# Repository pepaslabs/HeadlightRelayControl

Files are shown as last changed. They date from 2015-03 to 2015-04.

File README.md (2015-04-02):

# HeadlightRelayControl

A circuit board to control automotive headlight [relays](http://en.wikipedia.org/wiki/Relay).

## License

This board design is [Open-Source Hardware](http://www.oshwa.org/definition/).  It is licensed under the [MIT License](http://opensource.org/licenses/MIT).  It was designed by Jason Pepas.

# Board design v3

In this iteration of the board, the current-limiting resistors are replaced with constant-current sinks.

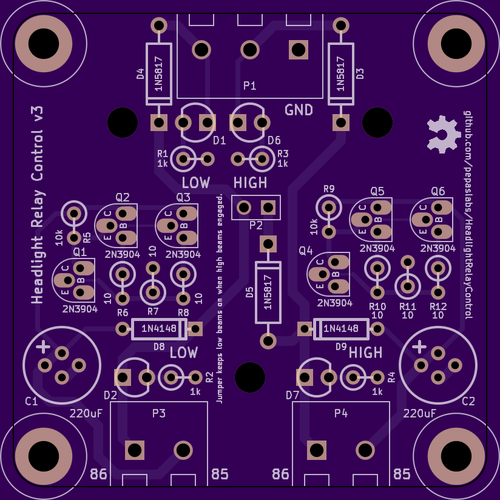
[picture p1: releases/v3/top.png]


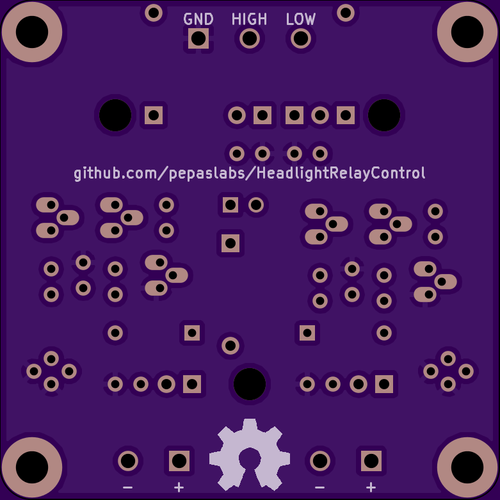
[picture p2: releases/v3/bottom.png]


(*Board renders courtesy of [OSHPark](https://oshpark.com/shared_projects/iHltO6hv)*)

## Gerbers

[gerbers.zip](releases/v3/gerbers.zip)

## Schematic

[PDF](releases/v3/HeadlightRelayControl_schematic.pdf).

# Board design v2

This was the first iteration of the design (which had no mistakes!).

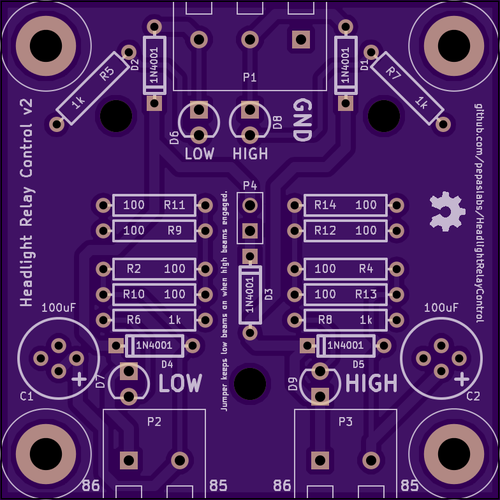
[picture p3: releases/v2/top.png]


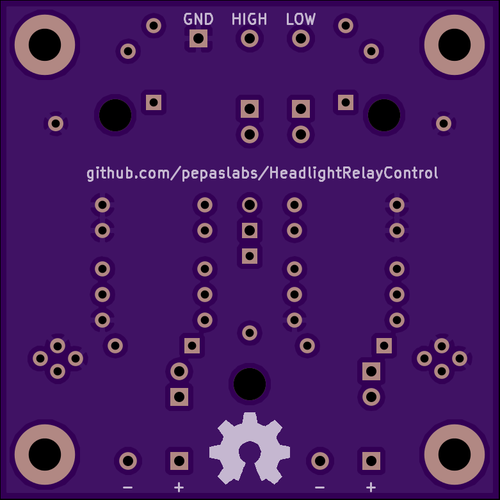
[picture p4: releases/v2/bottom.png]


(*Board renders courtesy of [OSHPark](https://oshpark.com/shared_projects/l73fKEFv)*)

## Gerbers

[gerbers.zip](releases/v2/gerbers.zip)

## Schematic

[PDF](releases/v2/HeadlightRelayControl_schematic.pdf).

# Board design v1

(This release had an error and is deprecated.)

# Designing this circuit in LTSpice

Let's design this circuit using [LTSpice](http://www.linear.com/ltspice).

Start with the following basic circuit.  The [inductor](http://en.wikipedia.org/wiki/Inductor) L1 represents the coil inside of the relay.

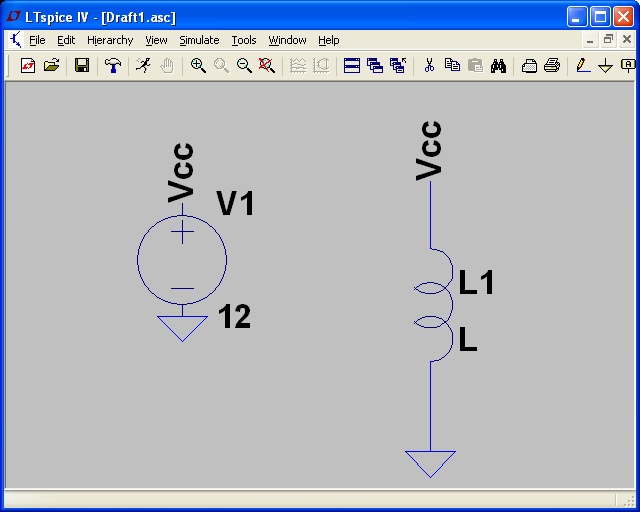
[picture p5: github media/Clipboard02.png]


## Specifying the relay coil parameters

Before we can simulate this circuit, we need to know some characteristics of the relay coil.  Specifically, we need to know the [inducatance](http://en.wikipedia.org/wiki/Inductance) and the [resistance](http://en.wikipedia.org/wiki/Electrical_resistance_and_conductance).

Here I've measured the inductance of a typical 12 Volt, 30 Amp automotive relay to be about 132 millihenries (using a cheap [LC100-A](http://www.ebay.com/sch/i.html?_nkw=LC100-A) meter from eBay):

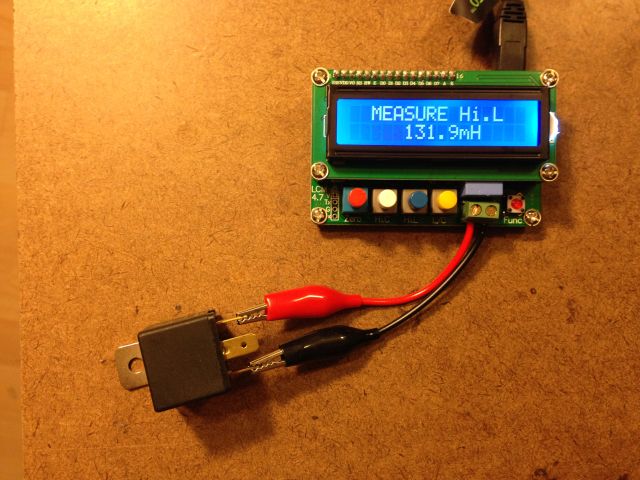
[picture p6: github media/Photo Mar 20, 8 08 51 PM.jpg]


Here, I've pulled up the [datasheet](http://www.te.com/commerce/DocumentDelivery/DDEController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) of a similar relay [listed on digikey.com](http://www.digikey.com/product-detail/en/1432785-1/PB680-ND/807757), where the resistance is listed as being 90 Ohms:

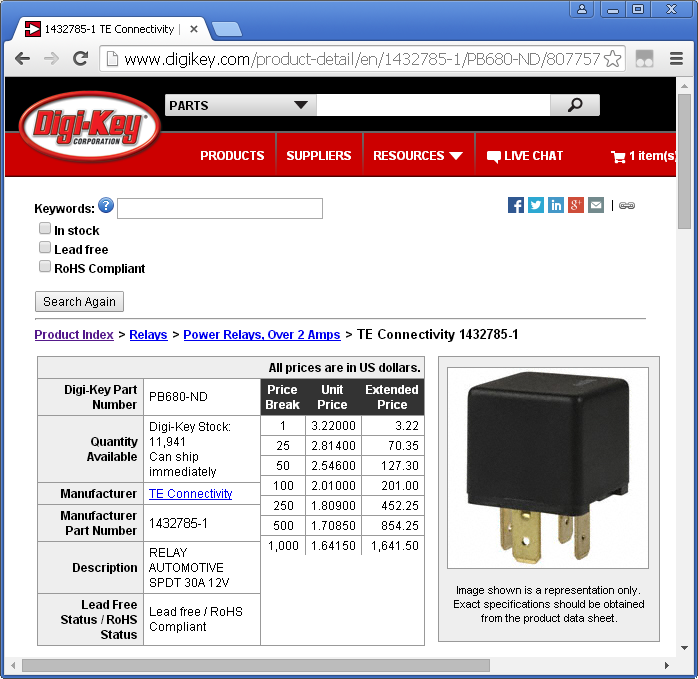
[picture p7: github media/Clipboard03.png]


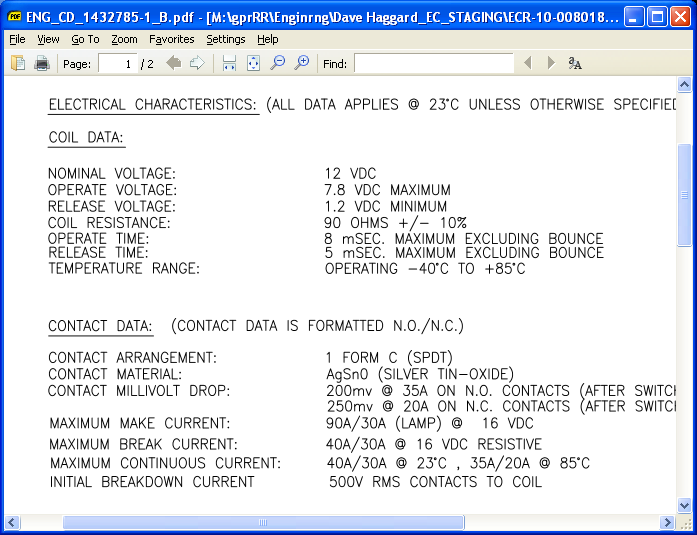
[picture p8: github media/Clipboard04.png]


Right-click on L1 and fill in these parameters:

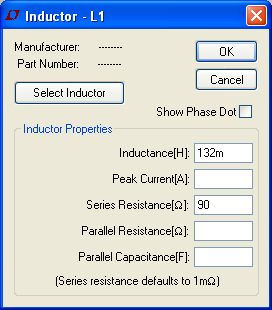
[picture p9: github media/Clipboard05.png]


We want to simulate turning this relay on.  We can do this by creating a **PULSE** voltage source which will switch from 0V to 12V at 10 milliseconds.  Right-click on V1, then click advanced and fill in these parameters:

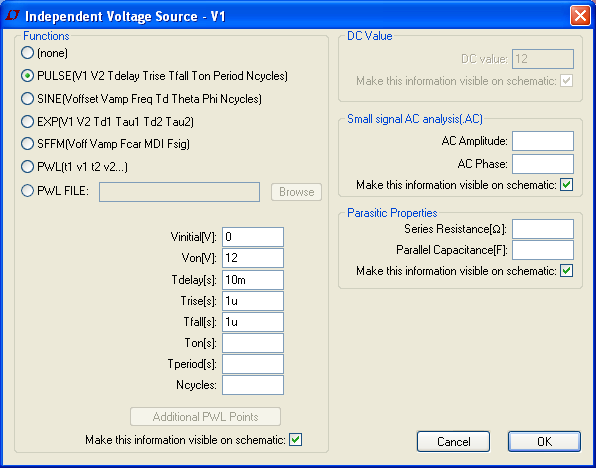
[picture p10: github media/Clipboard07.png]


Simulate the relay for 100 milliseconds

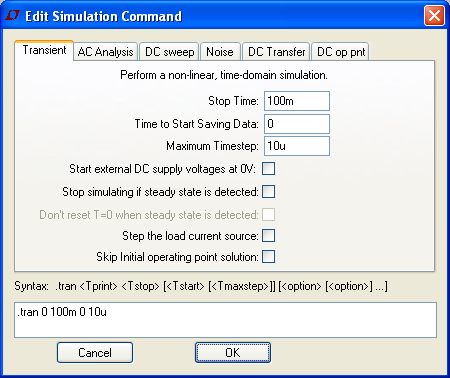
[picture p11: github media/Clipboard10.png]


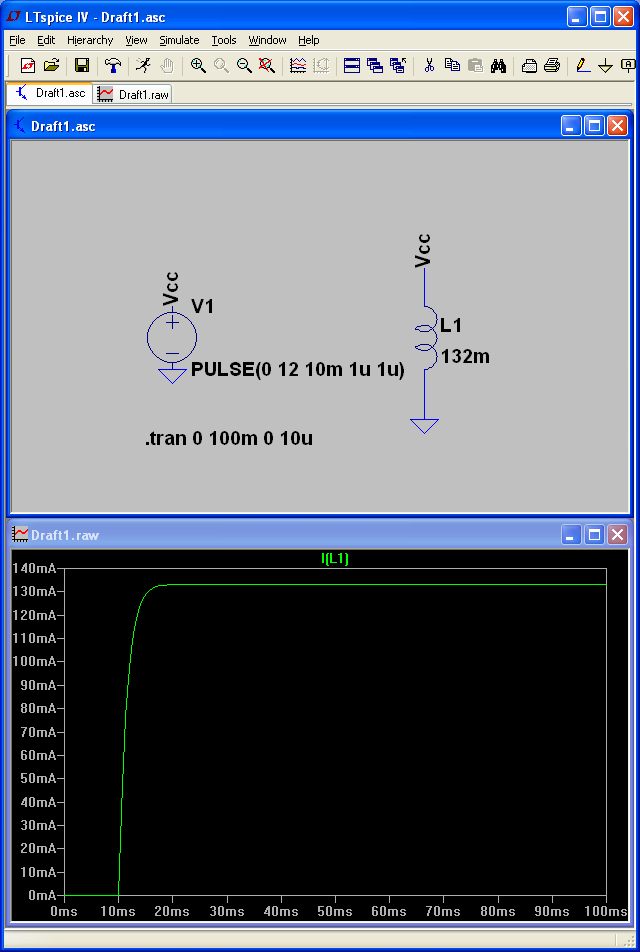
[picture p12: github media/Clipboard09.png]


Click on the green **I(L1)** label to create a cursor.  We can use the cursor to meausre the current, which is 133mA:

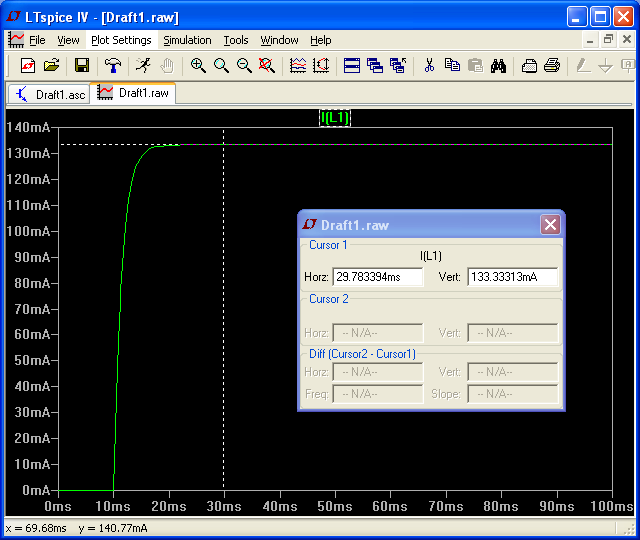
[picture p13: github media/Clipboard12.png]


## Optimization: PICK and HOLD current

If you've ever operated an automotive relay at full voltage for a long period of time, you know they can get pretty hot.

It turns out that isn't necessary.  A relay only needs a short burst of full voltage (actually, current) to get the armature moving (this is called the **PICK** current).  Once switched, it requires only a fraction of that current (typically less than half of **PICK**) to keep the relay on (the **HOLD** current).

### Current-limiting resistor

We can add a 100 Ohm current-limiting resistor after the relay coil:

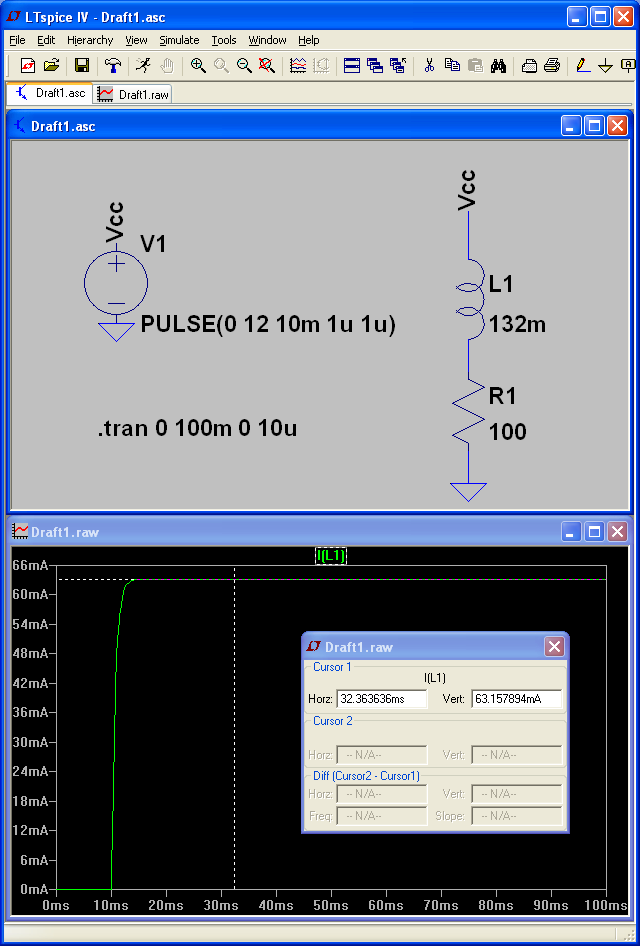
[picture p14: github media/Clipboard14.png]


Now we have our **HOLD** current (63mA), but we've lost our **PICK** current.  This means our relay might not turn on reliably.

How can we have both a **PICK** and a **HOLD** current?  There are a few ways to implement this optimization.

### PWM the coil

We could [PWM](http://en.wikipedia.org/wiki/Pulse-width_modulation) the coil, perhaps using a purpose-built [IC](http://en.wikipedia.org/wiki/Integrated_circuit), such as the [DRV120](http://www.ti.com/lit/ds/symlink/drv120.pdf) made by [TI](http://www.ti.com/).

However, there even simpler, more hobbyist-friendly solutions...

### Bypass the current-limiting resistor

The technique I decided to use was to bypass the current-limiting resistor with a capacitor.

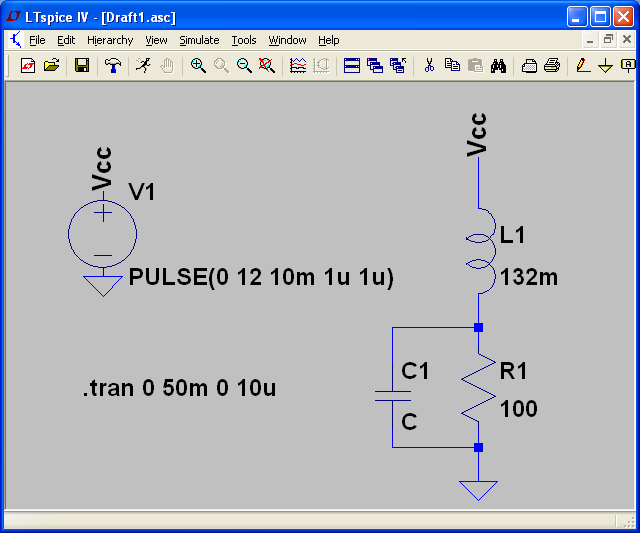
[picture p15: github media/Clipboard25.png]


I came across this trick in a [blog post](http://jumperone.com/2011/10/using-relays/) by [Phil Levchenko](http://jumperone.com/about/).  Be sure to also check out his [YouTube channel](https://www.youtube.com/user/JumperOneTV).

First we will try a 10uF capacitor.  We will esitmate its [ESR](http://en.wikipedia.org/wiki/Equivalent_series_resistance) to be 1 Ohm.

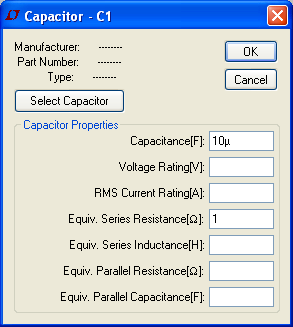
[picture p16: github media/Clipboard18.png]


Also, shorten the simulation window to just 50 milliseconds:

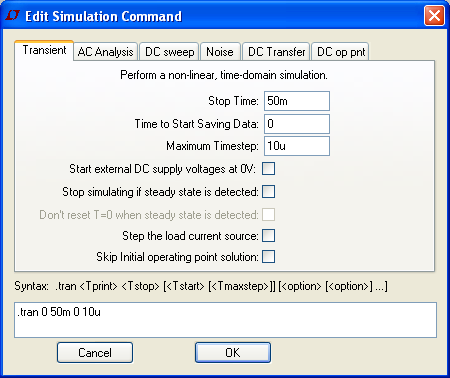
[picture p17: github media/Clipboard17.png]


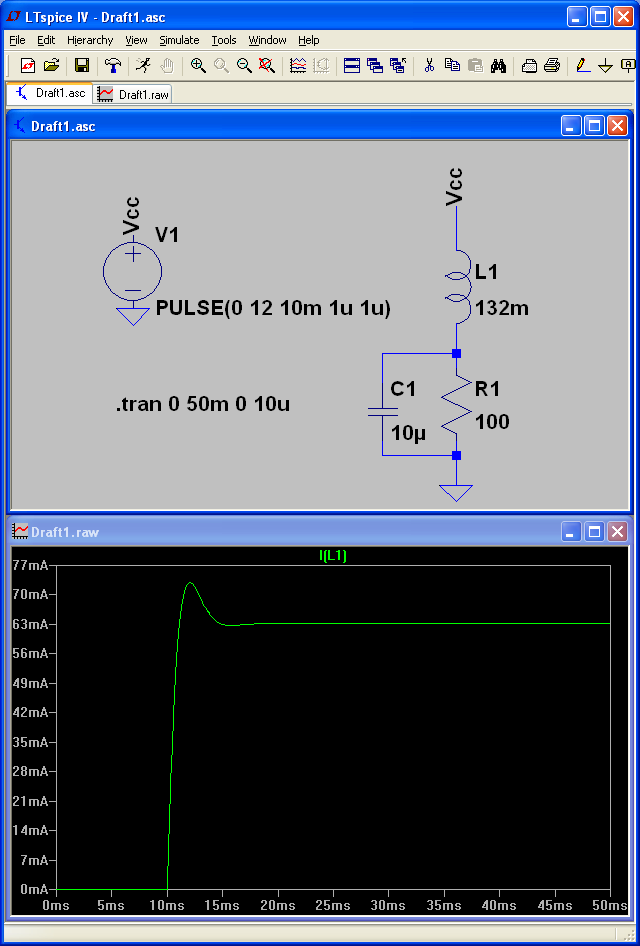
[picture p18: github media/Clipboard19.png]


It worked!  We have both a **PICK** and a **HOLD** current.

However, our **PICK** current is small and not very long in duration, so a 10uF capacitor might not be enough to give us reliable relay operation.

Based on the [datasheet](http://www.te.com/commerce/DocumentDelivery/DDEController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) mentioned above, we should shoot for a **PICK** current window of around 8 milliseconds in duration, and we want it to be much closer to 133mA.

Next we'll try a 100uF capacitor.  Estimate the ESR to be 100 milliohms.

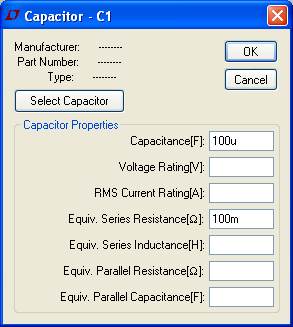
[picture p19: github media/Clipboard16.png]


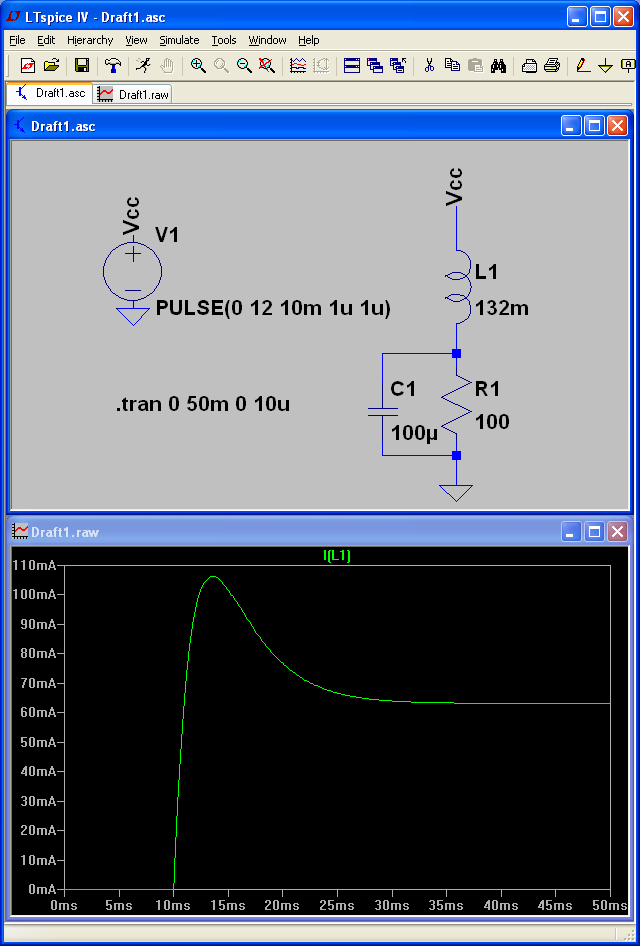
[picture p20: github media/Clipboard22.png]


That's a lot closer to what we want.  Use a cursor to get a more exact idea of what our 8ms **PICK** window looks like.

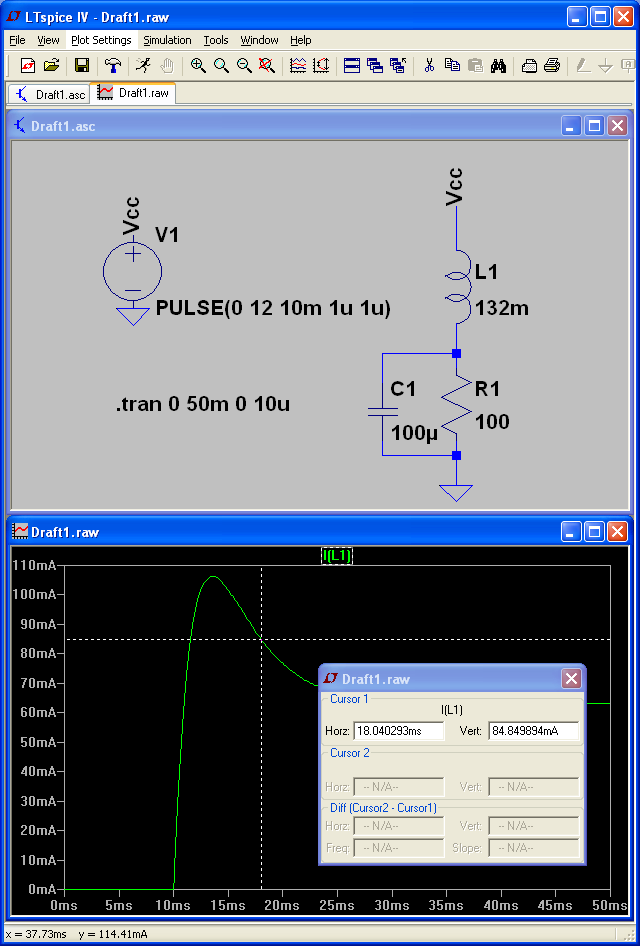
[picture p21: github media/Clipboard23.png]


Just to be thorough, we should also try a larger capacitor.  Try a 220uF (with 100mOhm ESR):

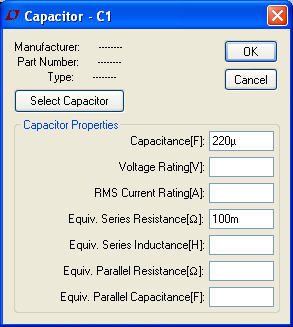
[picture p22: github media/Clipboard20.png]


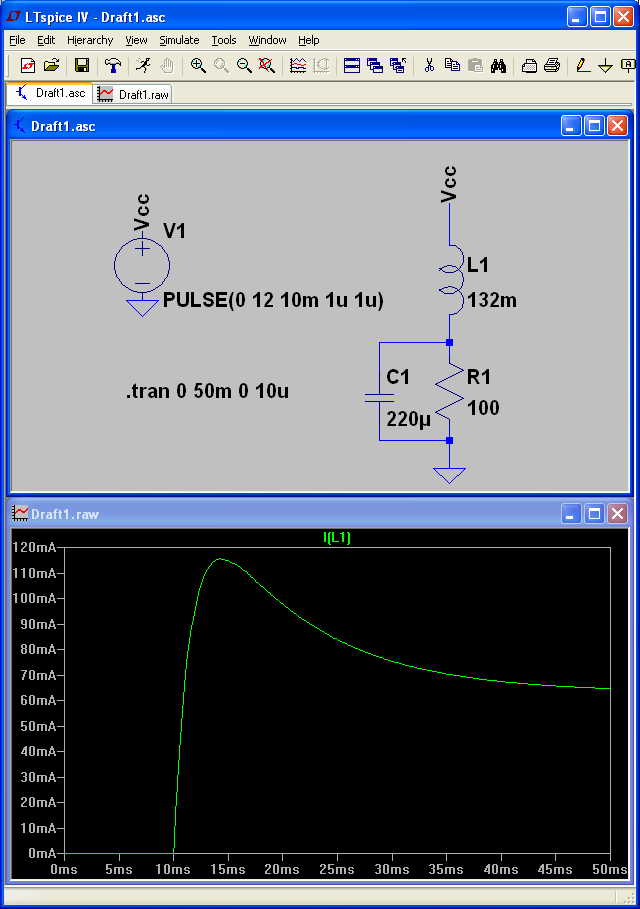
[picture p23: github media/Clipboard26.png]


It looks like either 100uF or 200uF would work well.

When designing a circuit, you'll often find yourself in these "[Goldilocks](http://en.wikipedia.org/wiki/The_Story_of_the_Three_Bears)" scenarios, trying to find the value that's "just right".  Its a good idea to get better at this, so that you can iterate on a design faster.

The quick-n-dirty way to do this is to triplicate your circuit and simulate all three at once.

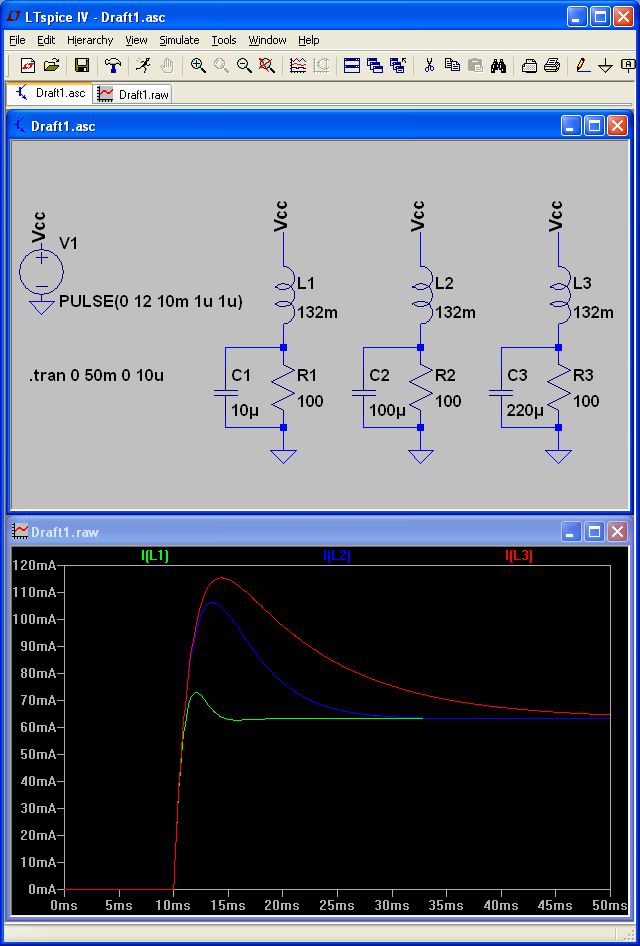
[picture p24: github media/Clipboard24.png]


Eventually though, you'll want to learn how to [step the parameters of your simulations](http://www.linear.com/solutions/1089).

## Freewheeling diode

What happens when we switch the relay off?

Anytime you interrupt current flowing through an inductor, it creates a (negative) voltage spike, a.k.a an [inductive "kickback"](http://www.coilgun.info/theoryinductors/inductivekickback.htm) as the magnetic field in the inductor collapses.  This spike can can reach dozens, hundreds, or even thousands of Volts, which can damage other components in your circuit.

### Simulating inductive kickback

Does our circuit suffer from inductive kickback?  Let's ask LTSpice!

In order to simulate that, we need to use a switch, which is slightly complicated in LTSpice.

#### Wait, why can't we just turn the PULSE source off at, say, 40 milliseconds?

That would set the **PULSE** source to 0 Volts.  It turns out that's not the same thing as turning the circuit off (see also [Three-state logic](http://en.wikipedia.org/wiki/Three-state_logic)).

When we set a voltage source to 0 Volts, it **actively drives** the circuit to 0 Volts.  That's not the same thing as just disconnecting the voltage source.  That's more like replacing the voltage source with a short-circuit (to ground).

#### Using a switch in LTSpice

Grab [switch.mod](https://github.com/pepaslabs/LTSpice-parts/tree/master/parts/switch) and follow [my tutorial](https://github.com/pepaslabs/LTSpice-parts/wiki/switch) on how to incorporate it into a circuit.

Modify your circuit so that the switch is connected to the inductor:

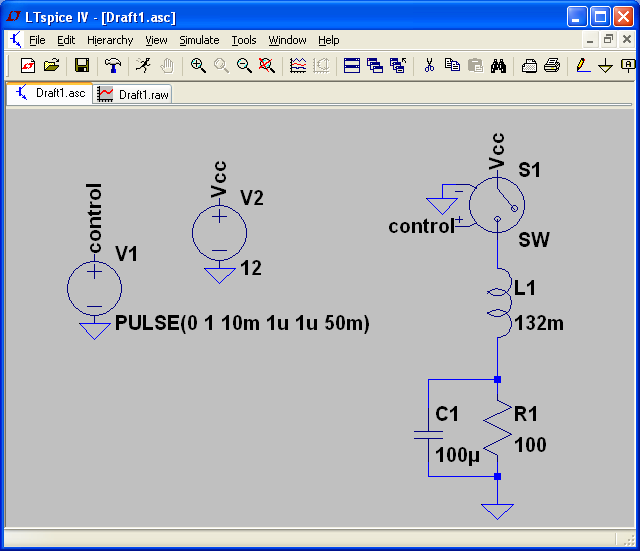
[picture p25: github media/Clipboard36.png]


Reconfigure the **PULSE** source to have a **Von** of 1 Volt and a **Ton** of 50 milliseconds:

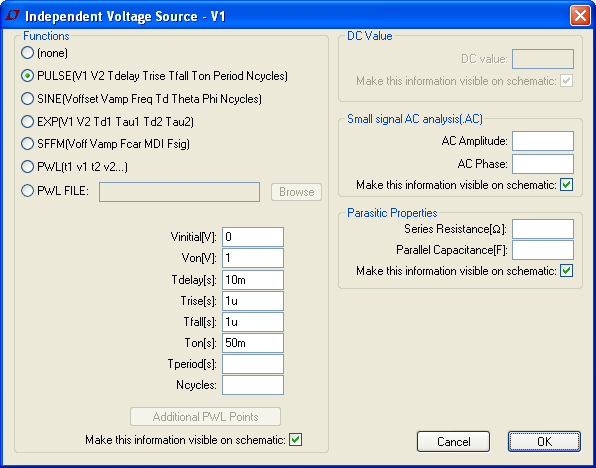
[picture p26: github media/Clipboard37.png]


Widen the simulation window to 100 milliseconds:



Run the simulation and probe the voltage between the switch and the inductor.

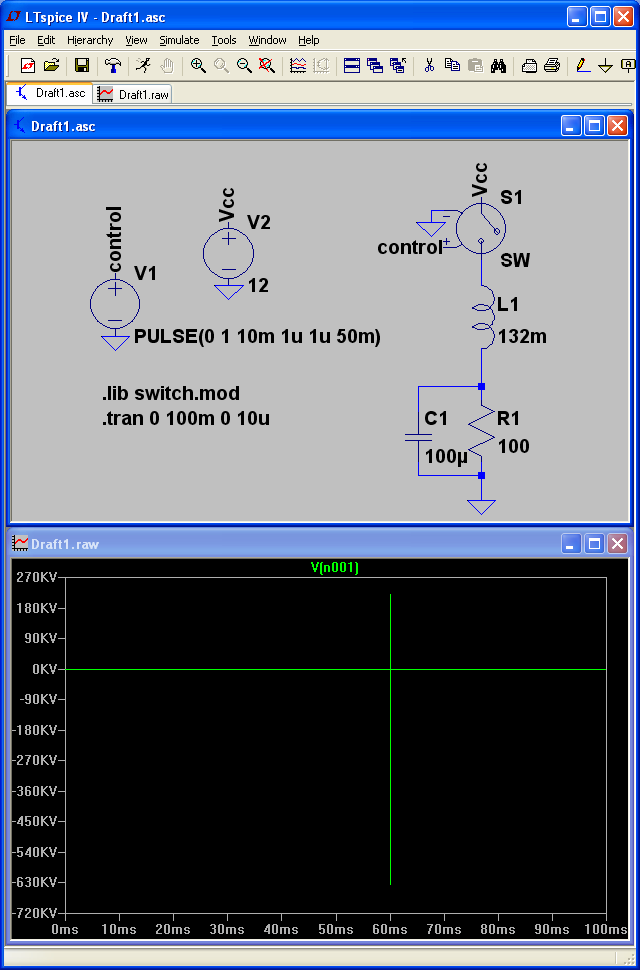
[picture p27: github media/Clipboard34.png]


Houston, we have a problem (inductive kickback!):

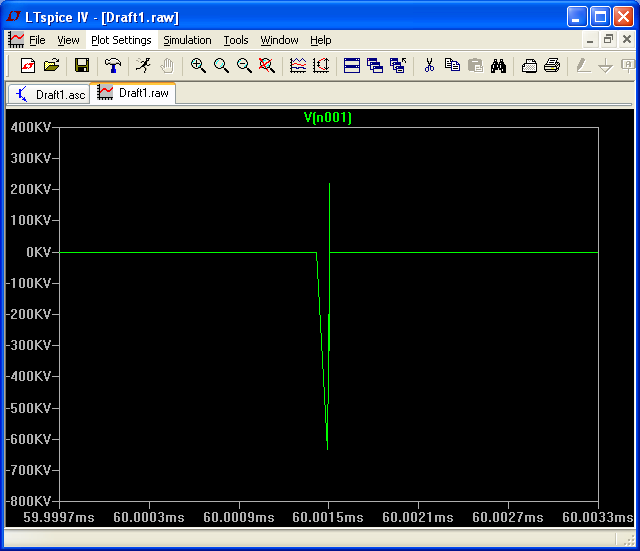
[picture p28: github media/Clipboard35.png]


(Note that with real-world components, you won't actually reach -600,000 Volts.  That only happens with idealized components in a simulator.).

Measuring the current through L1 gives you a better idea of what is going on here.  We are trying to instantaneously stop the current through the inductor, which causes the negative spike.

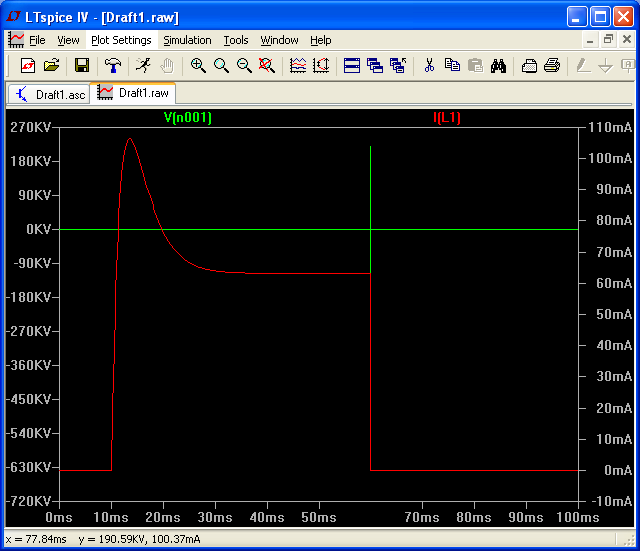
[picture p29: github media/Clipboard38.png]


### So how do we get rid of the inductive kickback?

Inductive kickback is typically mitigated by placing a [freewheeling diode](http://en.wikipedia.org/wiki/Flyback_diode) (also called a flyback diode or snubber diode) across the inductor.  The negative spike is dissipated through the diode, which "clamps" the spike to no more than the [forward voltage drop](https://learn.sparkfun.com/tutorials/diodes/real-diode-characteristics) across the diode (typically 0.65 Volts).

Place a diode across the inductor.  Right-click on the diode and make it a [1N4148](http://en.wikipedia.org/wiki/1N4148).

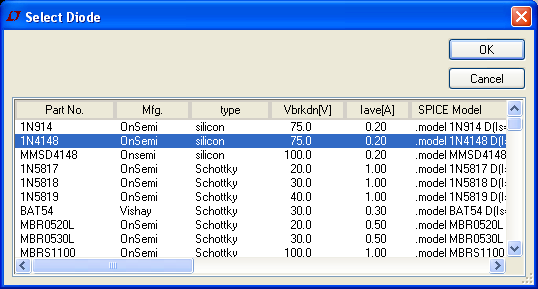
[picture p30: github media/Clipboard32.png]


Did it fix our negative voltage spike?

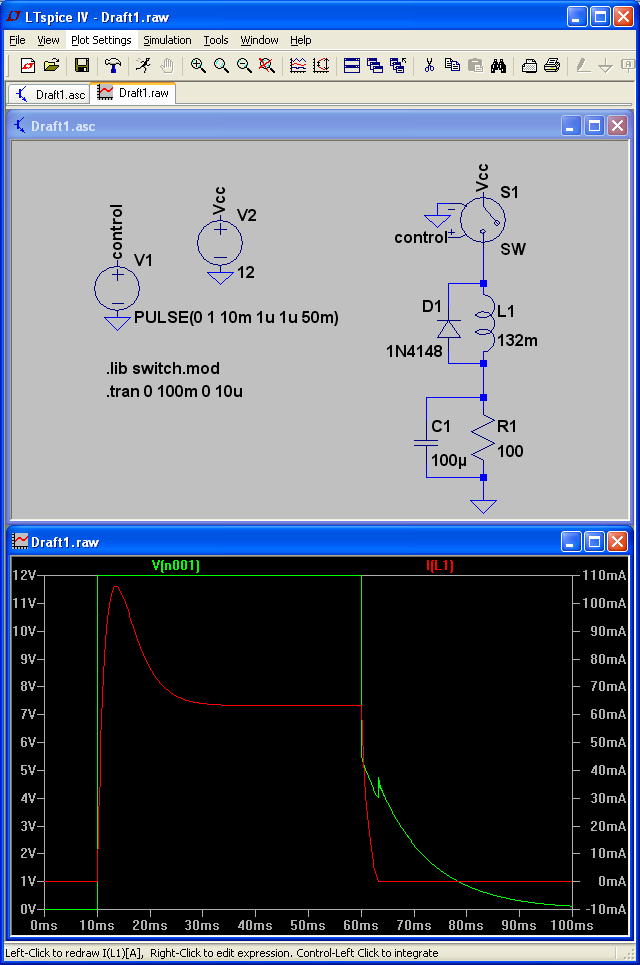
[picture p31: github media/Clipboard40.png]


Yup!

(Notice the funny blip where the decaying voltage suddenly jumps back up a bit.  Note also that it jumps up by exactly 1 forward diode drop, at exactly the point when current finishes decaying in the inductor.)

## Feature: When you turn on the high-beams, keep the low-beams on

This control board has a feature where the low beams stay on when the high-beams are engaged.  This was implemented using a [diode OR](http://en.wikipedia.org/wiki/Diode-or_circuit).

Before we can simulate this feature, we need to duplicate our relay control circuit (to simulate both low beam and high beam), and put in an incomplete diode OR circuit (which we will complete later).

### Setup low beam and high beam circuits

Make a copy of the relay coil control circuit:

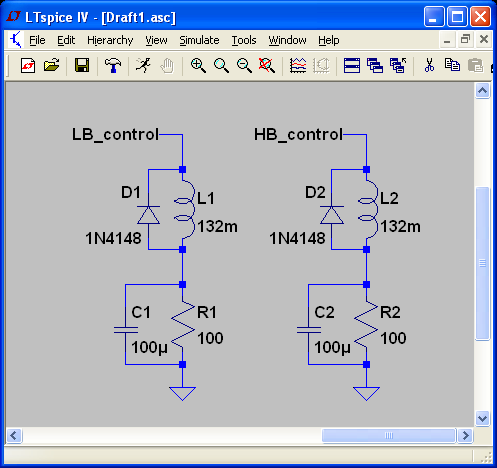
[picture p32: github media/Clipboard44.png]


Setup two switches:

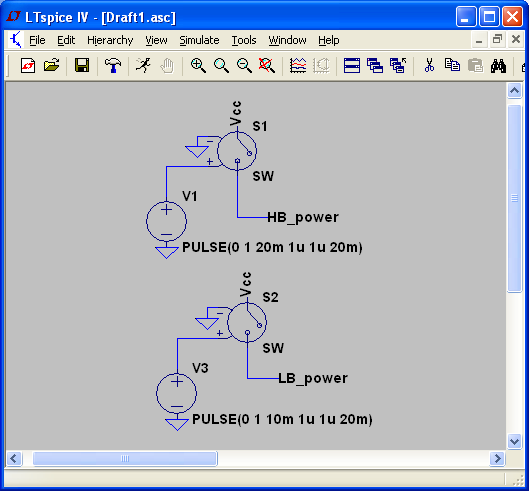
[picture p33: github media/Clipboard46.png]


Create the (incomplete) diode OR:

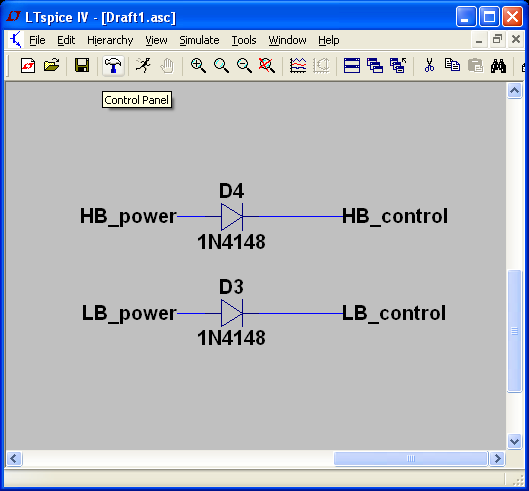
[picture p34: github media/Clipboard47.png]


The complete circuit should look like this:

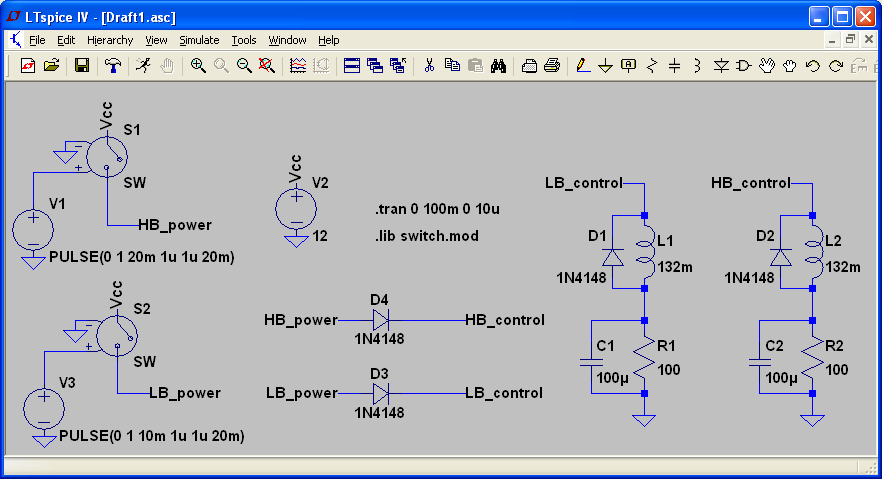
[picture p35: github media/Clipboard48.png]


Reconfigure the **PULSE** sources so that low beams turn on at 10 milliseconds for a duration of 20 milliseconds, and high beams turn on at 20 milliseconds for a duration of 20 milliseconds.  This will set up the following events:
* at T=10ms, low beams will turn on
* at T=20ms, high beams will turn on
* at T=30ms, low beams will turn off
* at T=40ms, high beams will turn off

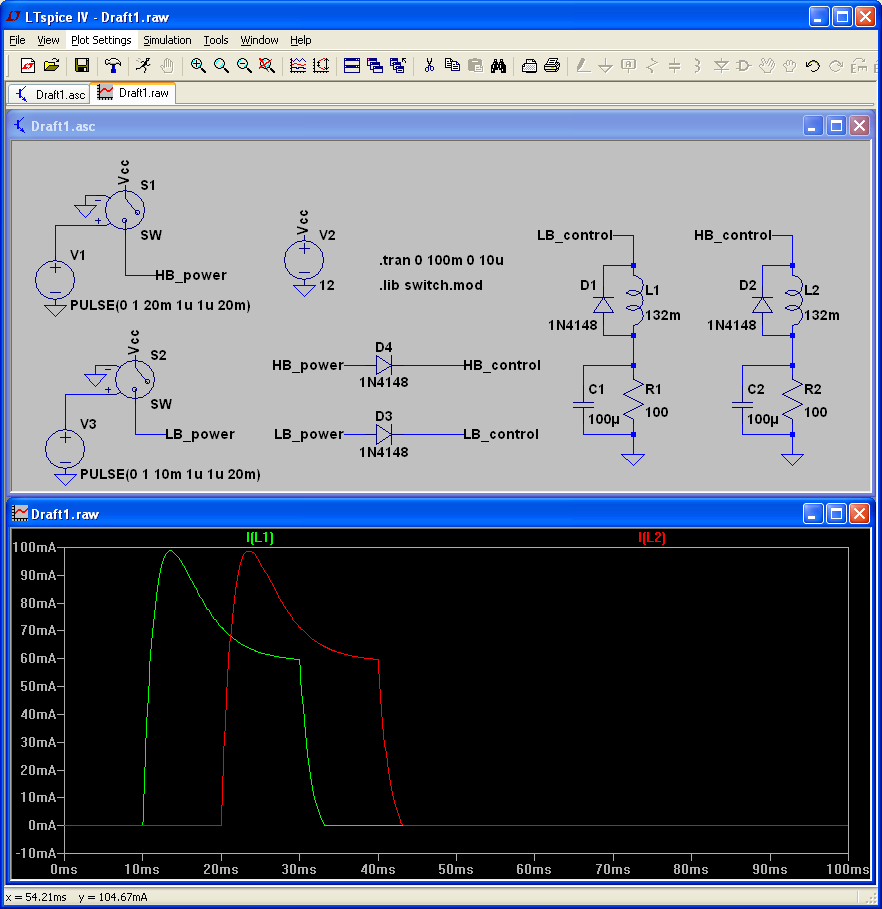
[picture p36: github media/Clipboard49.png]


Now, add the missing piece.  Complete the diode OR with an additional 1N4148:

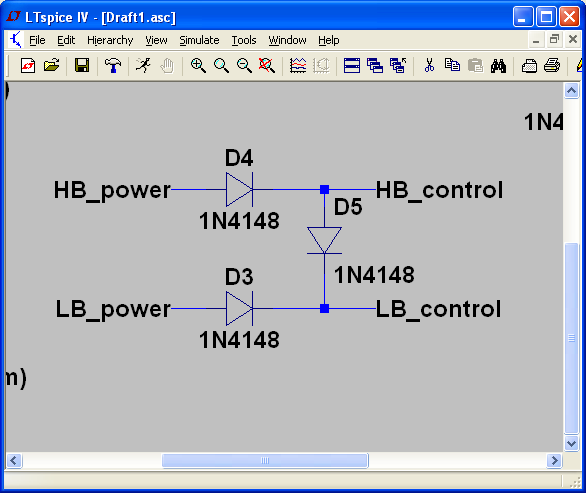
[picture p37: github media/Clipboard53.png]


Run the simulation again.  If the diode OR works, you should see the high beams prevent the low beams from turning off.

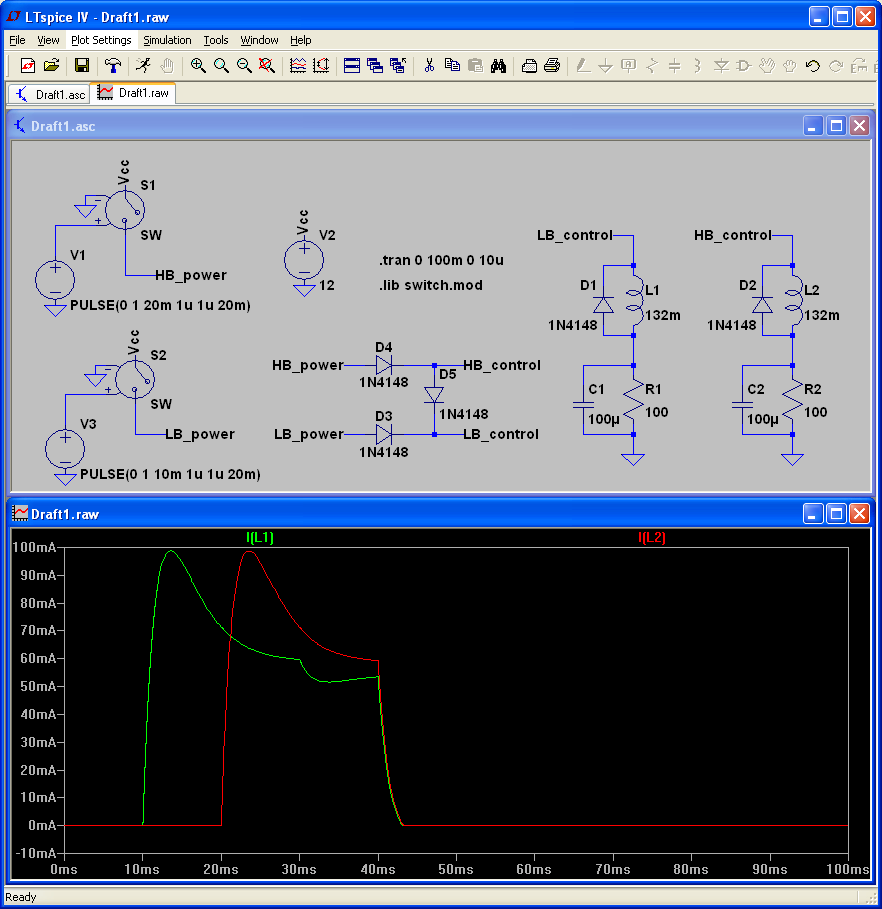
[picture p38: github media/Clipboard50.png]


Bingo!

### Investigating a glitch

However, notice that the **HOLD** current through the low beam relay coil dips a bit at the point in time where the low beams are being held on by the high beams (when LB_power shuts off).

In our particular case, this dip isn't large enough for us to worry about (such a small dip won't cause the relay to turn off).

But let's examine what causes this anyway.  Create two additional traces which monitor LB_control and HB_control:

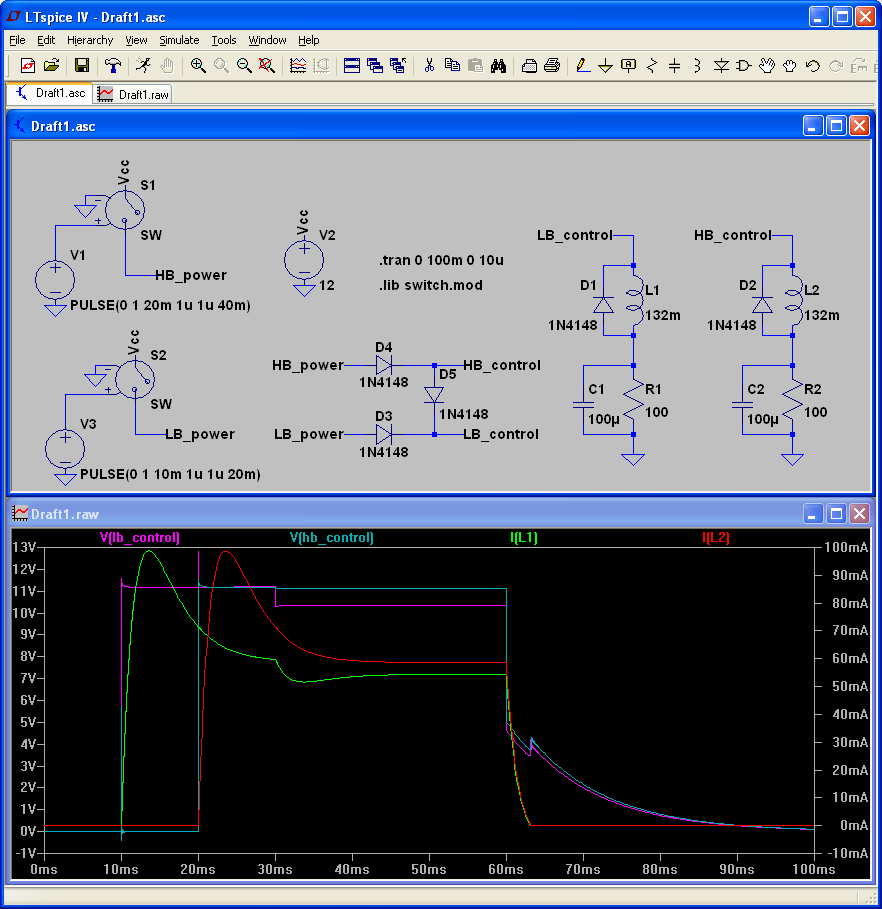
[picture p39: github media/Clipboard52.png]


Ah, now this makes sense.  When LB_power shuts off, the current which keeps the low beam relay on has to go through D4 and then through D5.  This means it suffers a second diode drop (another 0.65 Volts) before it reaches the low beam coil.  That's what accounts for the slight dip in coil current.

This also means that when the high beams are keeping the low beams on, the current for both relay coils has to go through D4.  This provides us a nice segue into considering the power dissipation...

## Power dissipation

### Diode power dissipation

Let's examine the power dissipation in D3, D4, and D5.  Run a simulation and ALT-click on the diodes to create power dissipation traces.

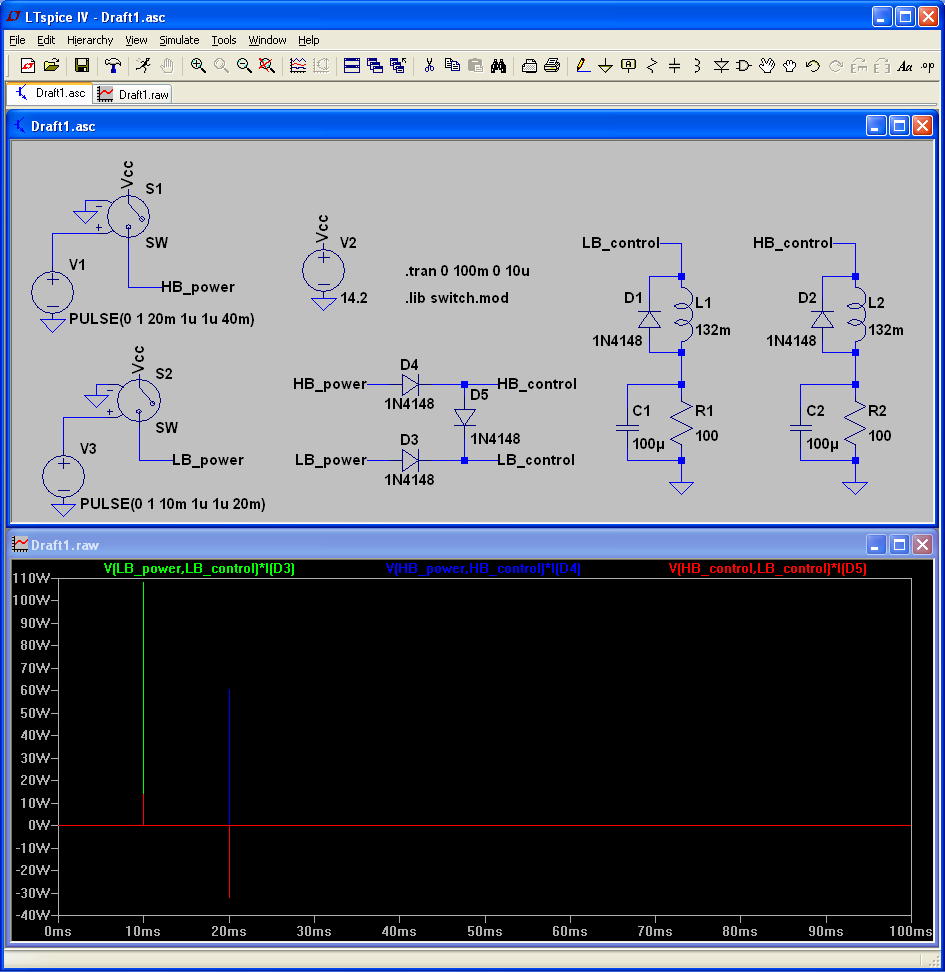
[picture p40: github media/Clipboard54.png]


The result is a bit confusing, because there are infinitesimally breif moments where the current spikes up over 100 Amps, which throws off the scale of the plot.  (We can safely ignore these spikes, as our real-world components will have parasitic capacitance and inductance which will greatly tame these spikes.  What remains will be so brief that it will be safely absorbed by the thermal mass of the diode).

Use the zoom tool to bring the situation to light:



Now we have a better picture of what's going on.  The worst case will be seen by D4 when the current for both high and low beam relay coils is flowing through it, at which point it will be dissipating 120 milliWatts.

Can the 1N4148 handle this?  Better check the datasheet.



Pulling up the [datasheet](http://www.vishay.com/docs/81857/1n4148.pdf) of a typical 1N4148, we see it is rated handle a dissipation of 440 milliWatts when TL (the [temperature of its leads](http://www.st.com/web/en/resource/technical/document/application_note/CD00183570.pdf)) is 45C (e.g., when it is in a hot environment).

For components like resistors and diodes, its a good design rule of thumb to [stay under half of the max rated dissipation](http://www.play-hookey.com/dc_theory/resistors/components_resistors.html).  For a 1N4148, that's 220mW, so we shouldn't have a problem at 120mW.

### Resistor power dissipation

Let's examine the power dissipation one of the current limiting resistors, R1.  ALT-click R1 to plot the power dissipation.



At 500mW, we should specify a 1 Watt resistor.

However, we want to keep this as hobbyist-friendly as possible, and a hobbyist is much more likely to have 1/4 Watt resistors on hand.  A trick we can use is to "quad-up" the resistor: replace the single resistor with four resistors in a series-parallel configuration.  This keeps the overall resistance value the same, but quadruples the power rating.  Each 1/4 Watt resistor would dissipate 125mW, which just meets our half-max design rule.



# Prototype

Now that we're reasonably sure our design is sound, the next step is to make a prototype.

I prefer to use [Manhattan style](https://www.google.com/search?q=manhattan+style+prototyping) construction on [copper clad](http://www.ebay.com/sch/i.html?_nkw=copper+clad).



Note that I used [terminal blocks](http://www.taydaelectronics.com/connectors-sockets/terminal-blocks/pcb-mount.html) to hold the bypass capacitors, so that I could easy swap them out and try different values of capacitance.

# Verification

Now that we have a prototype, we can compare its behavior to our LTSpice simulation.

Here, I've used a Vcc of 12V, using 220uF bypass capacitors, and I'm probing the voltage across the relay coil.



Pretty close!

Here's how I set this up in LTSpice.  To measure the voltage across a component (in this case, across L1), you have to manually edit the expression of a trace.

Create traces for the top and bottom of the L1 indcutor.  This identifies the node names for us.



Now right-click the **V(lb_control)** label to edit its expression.



Edit the expression to give you the difference in voltage.



Viola!



However, the scale of the plot does not line up with the results on the oscillosope.  Right click the plot and choose "Manual limits".  My scope has 12 horizontal divisions, and I'm at 10ms per division, so the LTSpice plot should be 120ms wide.  My scope has 8 vertical divisions and I'm at 2V per division, with a -6V offset, so my LTSpice plot should range from -2V to 14V in order to match the scope.





# See also:

* http://electronics.stackexchange.com/questions/34561/what-are-some-ways-to-use-relays-more-efficiently

# Background: The need for this circuit

## Why did I make this circuit?

After upgrading the aging, dim headlights on my (1997 Dodge Ram) pickup truck with an HID headlight kit from eBay, I ran into a problem: the stock headlight switch couldn't handle the higher current load of the HID headlights.

The spade connector on the headlight switch got so hot that the plastic which holds it in place started to melt.  Some of the melted plastic interfered with the connection, and the connector was no longer being securely held in place.  The result was that you had to wiggle the switch to get the headlights to come, and you could occaisionally smell burning plastic.  Eventually, the connection stopped working entirely.





## Why did the stock headlight switch fail?  Its hard to beleive the HIDs drew THAT MUCH more current...

True, there's more to this story than a simple matter of higher current draw.

Stock halogen headlights are spec'ed at 55 Watts.  If we assume that spec is for 12 Volts (rather than the 14.2 Volts you'd find in a running car), that means each lamp is drawing 55 / 12 = roughly 4.6 Amps.

The HID ballasts I use claim a max current draw of 10 Amps (they don't always draw 10 Amps, but they can go that high).  That's potentially more than twice the current which the stock headlight switch and wiring were designed around.

### HID ballasts look like a constant-wattage load

However, this problem is compounded by the fact that the HID ballasts are basically a constant-current supply, which means they look like a constant-wattage load to your car's electrical system.  This means that if you try to feed the ballast a lower voltage, it will simply draw more current to make up for it.  That's why they stay the same brightness even if your voltage droops a bit.

Resistive loads (like a traditional halogen bulb) don't behave like this.  If you lower the voltage, they draw fewer amps (and get dimmer).  If I had put 100 watt halogen bulbs in my truck, that would be bad (because they would try to draw 100 / 12 = 8.3 Amps), but it wouldn't be as precarious as the situation created by the HID ballasts.  Here's why:

When we turn on the 100 Watt halogen bulbs, they would draw 8.3 Amps.  The headlight switch (particularly the spade connector) and the wiring would start to heat up because we are drawing more current than they were rated for.  As they heat up, and their resistance would increase, which would create a voltage drop.  So now your bulbs only see maybe 10 Volts.  This means they draw less current, which means the headlight switch and wiring could start to cool down a bit, and eventually the whole system would settle out at some equilibrium.  This is how linear, resistive loads work.

### Thermal runaway

HID ballasts don't work like that.  The ballasts say their max draw is 10 Amps, but let's assume their normal, 12 Volt draw is only 6 Amps (72 Watts).  What happens when we turn them on?  Initially, the headlight switch and wiring aren't hot, and their resistance is low, and the HID ballast sees pretty close to 12 Volts, and draws 6 Amps.  But even 6 Amps is more than what the stock switch and wiring was designed to handle, so they start heating up, increasing in resistance, and creating a Voltage drop.  The HID ballasts are now only seeing 10 volts, and they compensate by increasing their current draw to 7.2 Amps (still 72 Watts).  This increased current draw causes the switch and wiring to heat up even more, become more resistive, and create an even bigger drop.  The ballast now sees only 8 Volts, and responds by drawing 9 Amps (still 72 Watts).  And now the switch and wiring heat up even more, and so on, and so on...

This situation is referred to as "thermal runaway".  The process would keep going indefinitely, except that the HID ballasts are designed with a safety mechanism where they will refuse to draw more than 10 Amps.  But at that point, the headlight switch and wiring are already hot enough to start burning the plastic and damaging the switch.

### Solution: use relays!

The solution to all of this is to use relays, which are high-current switches which are operated by a small current.  Typical automotive relays are rated to handle 30 Amps (more than enough for our HID ballasts) and they are typically controlled by about 0.125 Amps (125 milliamps).  This looks like a tiny, tiny load to your headlight switch, which means it won't even get warm, let alone hot enough to self-destruct.

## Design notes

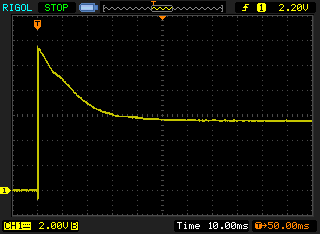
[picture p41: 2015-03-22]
github media/NewFile0.png

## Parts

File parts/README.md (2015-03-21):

KiCADParts
==========

A collection of KiCAD schematic symbols and component footprints which I have created / tweaked / used.

## Design Constraints / Preferred Values / Conventions

* Label size X / size Y / thickness ratio: 1 / 1 / 0.2
 * Preferred component value label size X / size Y / thickness: 0.03" / 0.03" / 0.006"
 * Minimum component value label size X / size Y / thickness: 0.025" / 0.025" / 0.005"
* Outline thickness: 0.01"

## Pads

* Ratios:
 * **_A_**: Size X: 1, Size Y: 1, Offset Y: 0
 * **_B_**: Size X: 1, Size Y: 1.5, Offset Y: 0.25
 * **_C_**: Size X: 1, Size Y: 2, Offset Y: 0

### 0.060" nominal pads

0.059 pads

Pads sized just under 0.060" (allows routing a 0.020" trace without violating DRC).

 * **_059A_**: Size X: 0.059", Size Y: 0.059", Offset Y: 0
 * **_059B_**: Size X: 0.059", Size Y: 0.0885", Offset Y: 0.01475"
 * **_059C_**: Size X: 0.059", Size Y: 0.118", Offset Y: 0

Drill size is 0.032" (the KiCAD default), which is used for:
 * 1/4W resistors
 * small signal diodes
 * ceramic and small electrolytic capacitors
 * DIP leads
 * TO-92 leads

### 0.070" nominal pads

0.069 pads

Pads sized just under 0.070" (allows routing a 0.010" trace without violating DRC).

 * **_069A_**: Size X: 0.069", Size Y: 0.069", Offset Y: 0
 * **_069B_**: Size X: 0.069", Size Y: 0.1035", Offset Y: 0.01725"
 * **_069C_**: Size X: 0.069", Size Y: 0.138", Offset Y: 0

Drill size is 0.040", which is used for:
 * 1/2W resistors
 * TO-220 leads

### 0.080" nominal pads

0.079 pads

Pads sized just under 0.080" (does not allow routing traces).

 * **_079A_**: Size X: 0.079", Size Y: 0.079", Offset Y: 0
 * **_079B_**: Size X: 0.079", Size Y: 0.1185", Offset Y: 0.01975"
 * **_079C_**: Size X: 0.079", Size Y: 0.158", Offset Y: 0

Drill size is 0.056", which is used for:
 * TO-218 leads
 * TO-247 leads

## Footprints

resistors_PL.mod

DIP_PL.mod

transistors_PL.mod

TO-220_PL.mod

## License

Parts which I have created are released under the [MIT License](http://opensource.org/licenses/MIT).  Parts which I have modified are subject to their original license.

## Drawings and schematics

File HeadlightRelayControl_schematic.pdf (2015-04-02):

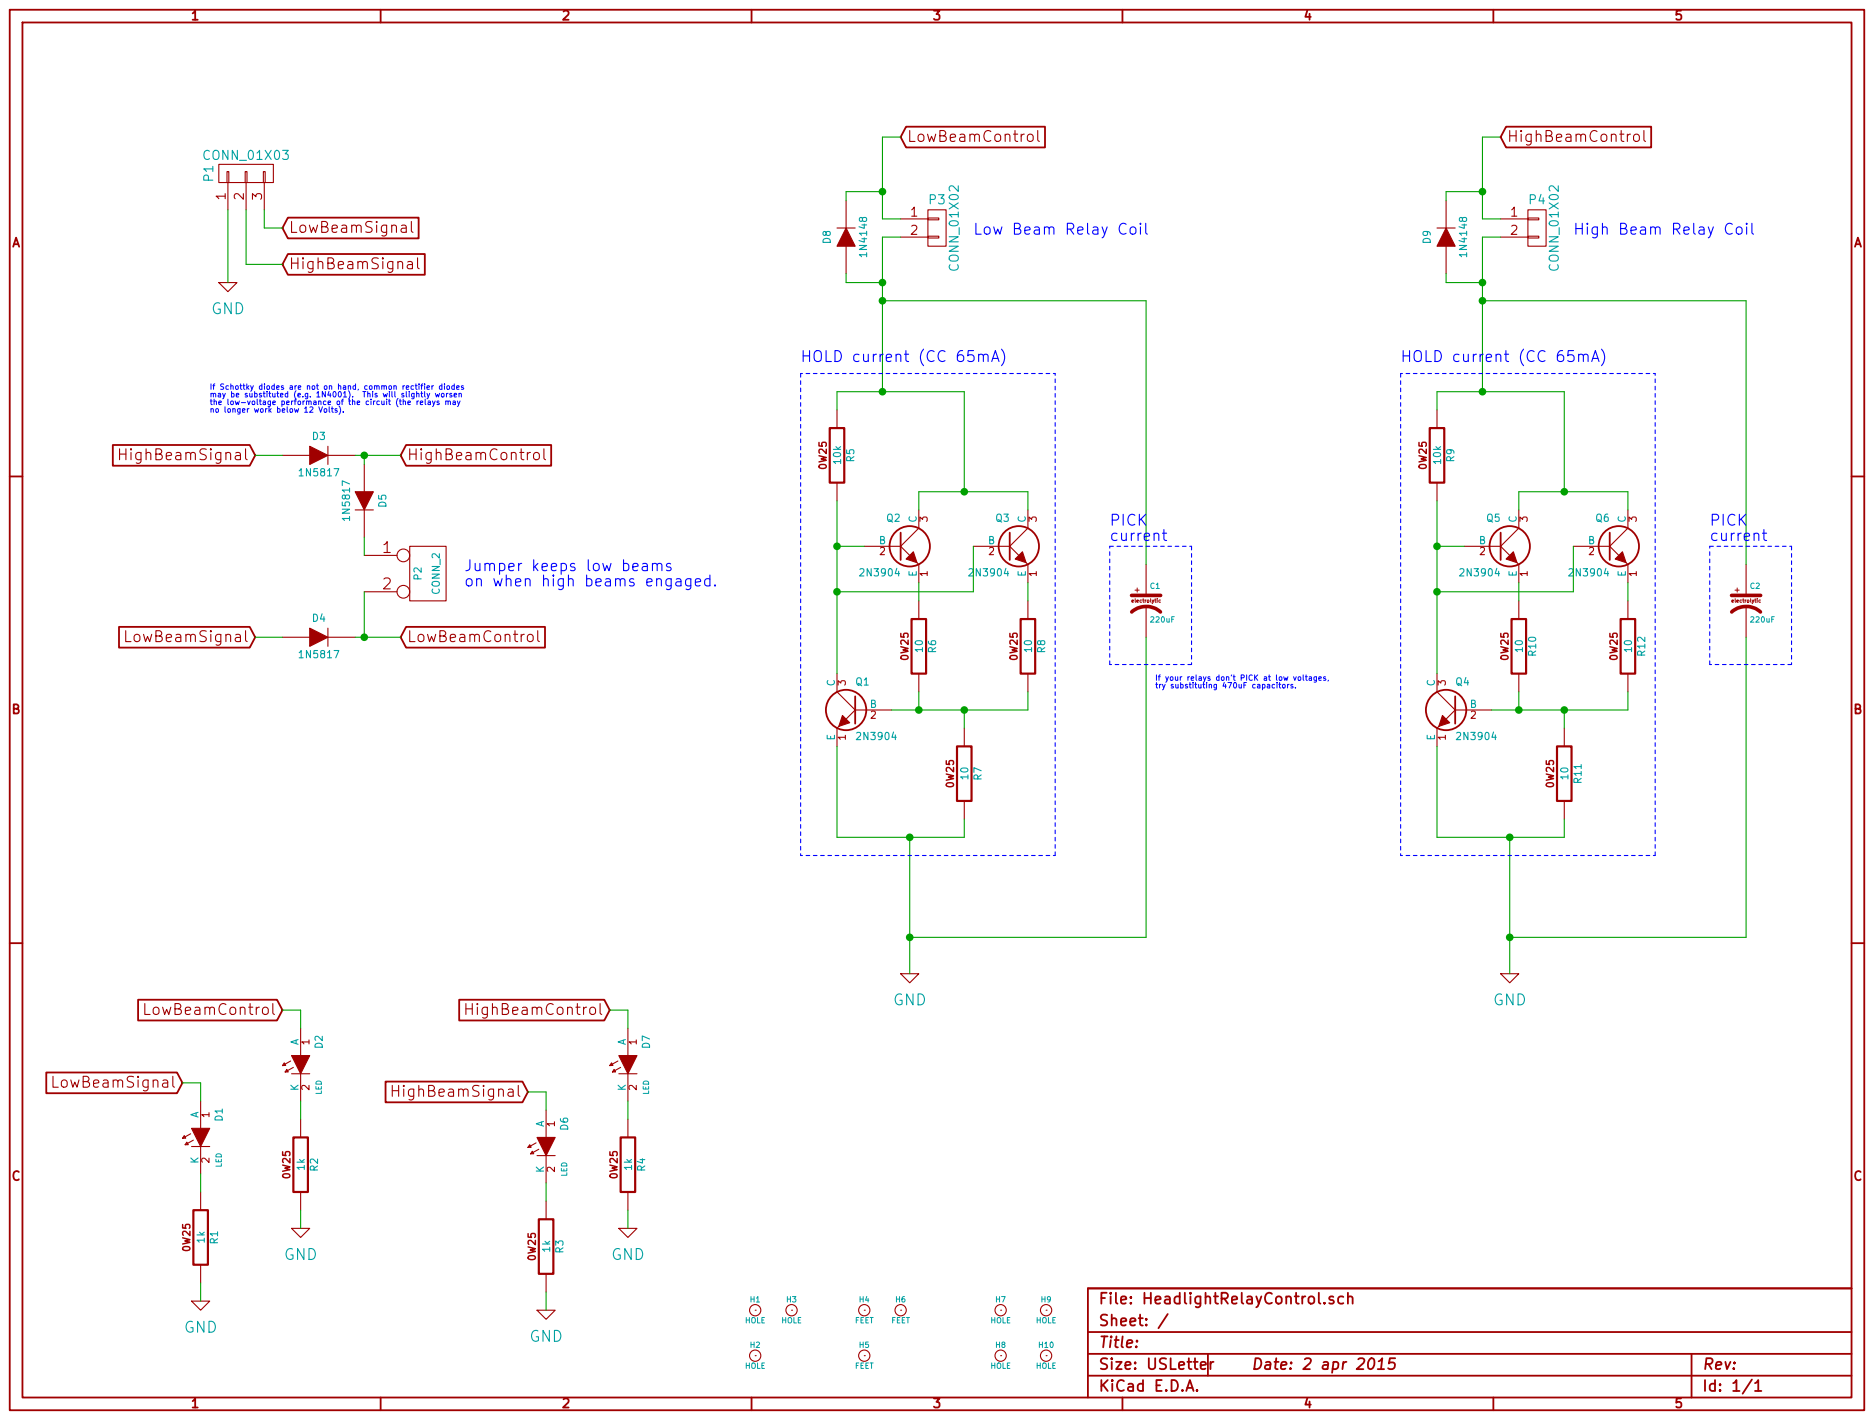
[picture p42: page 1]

Low Beam Relay Coil

If Schottky diodes are not on hand, common rectifier diodes may be substituted (e.g. 1N4001). This will slightly worsen
the low-voltage performance of the circuit (the relays may no longer work below 12 Volts).

Jumper keeps low beams

If your relays don't PICK at low voltages,
try substituting 470uF capacitors.

Id: 1/1 Title: File: HeadlightRelayControl.sch
Sheet: /

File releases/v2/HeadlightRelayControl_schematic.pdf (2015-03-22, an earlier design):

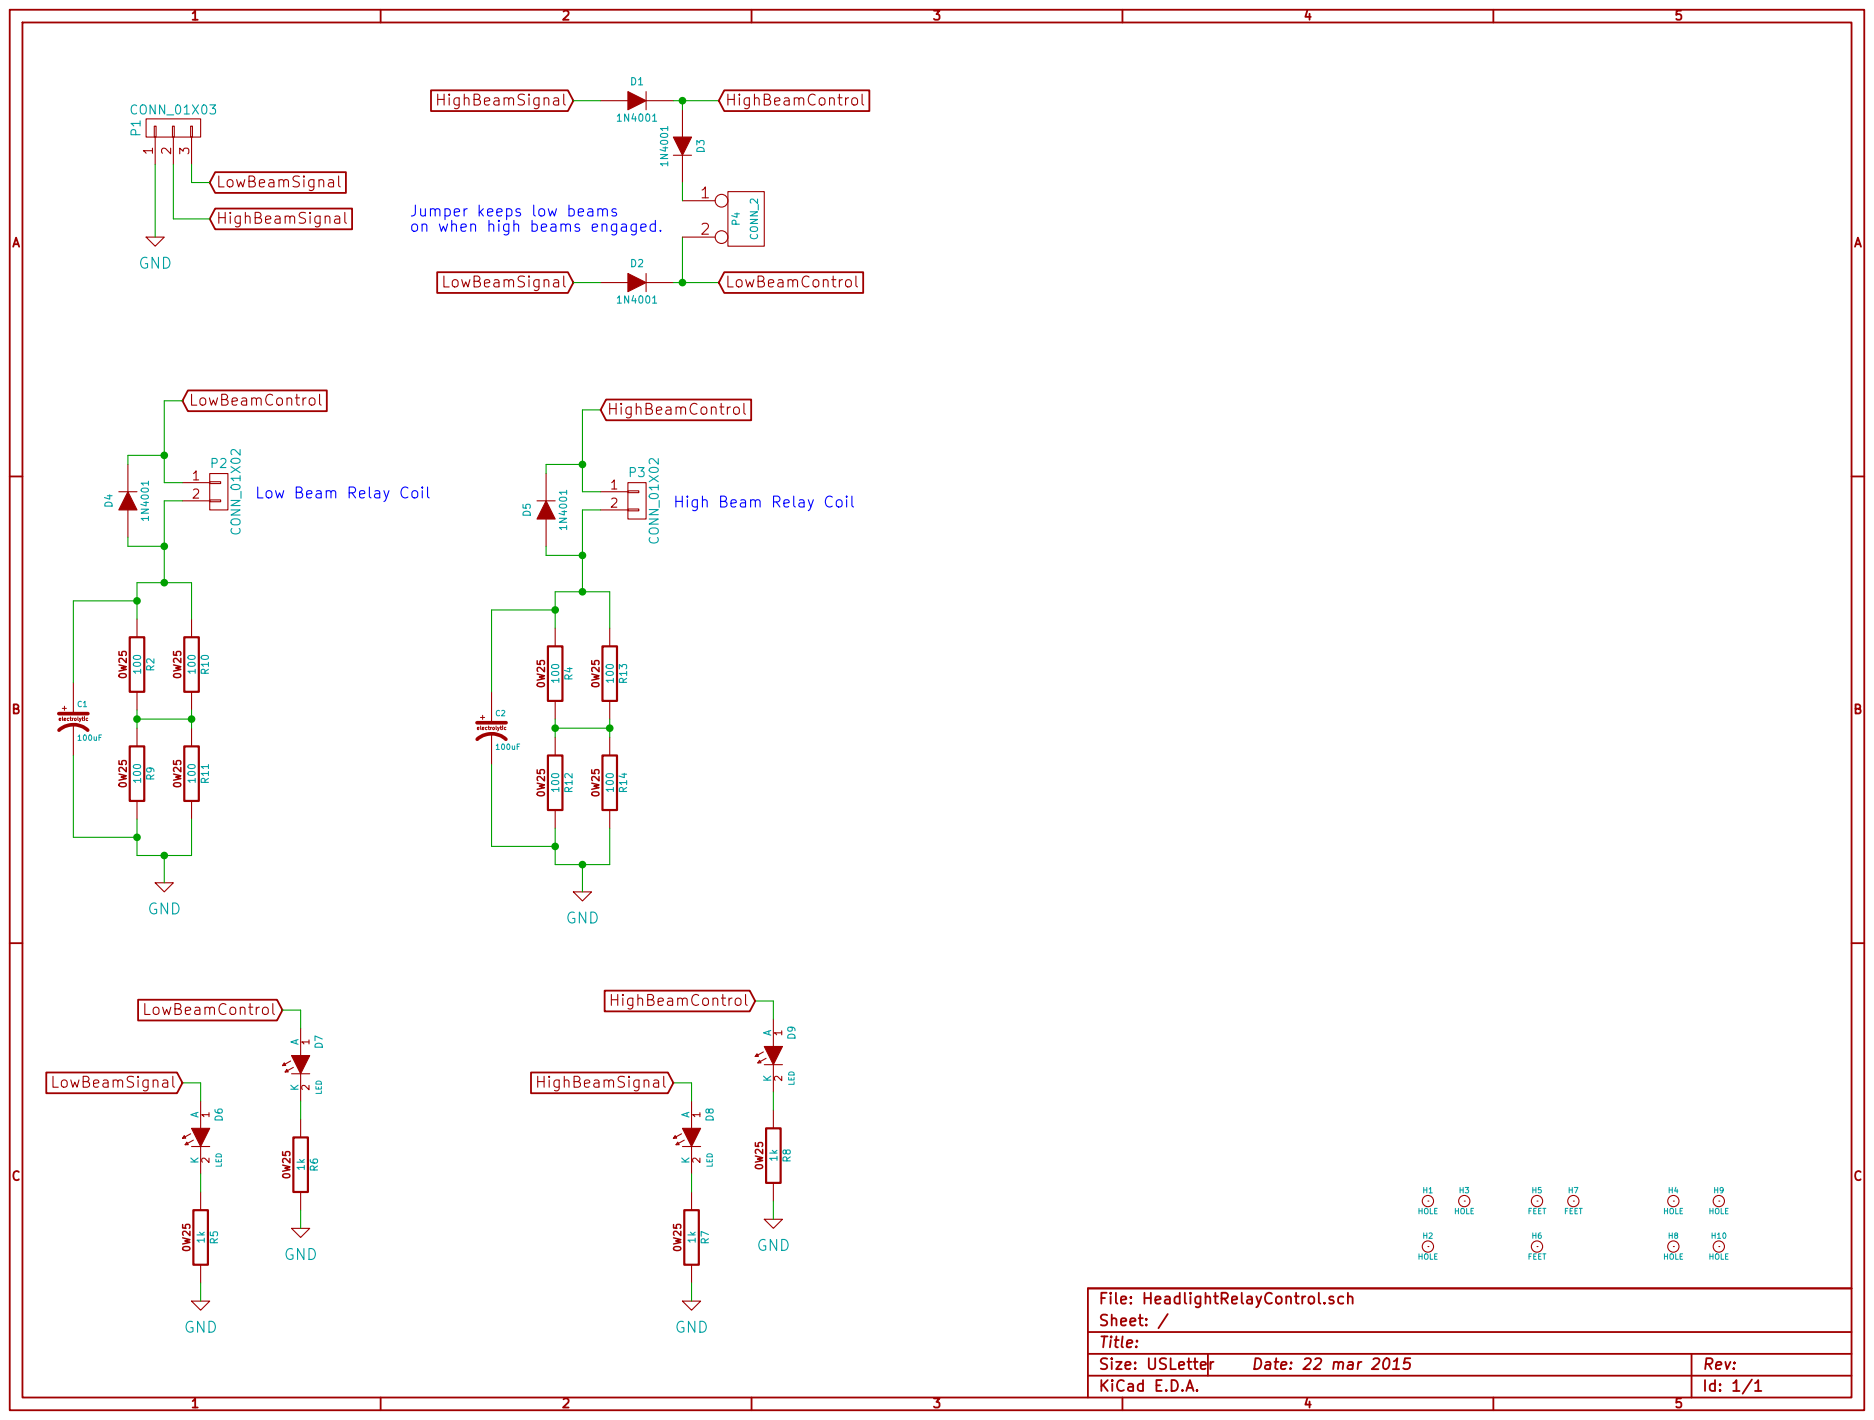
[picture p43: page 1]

Jumper keeps low beams
on when high beams engaged.

Id: 1/1 Title: File: HeadlightRelayControl.sch
Sheet: /

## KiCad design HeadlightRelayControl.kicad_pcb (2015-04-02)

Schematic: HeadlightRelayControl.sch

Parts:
C1, C2: 220uF
D1, D2, D6, D7: LED
D3, D4, D5: 1N5817
D8, D9: 1N4148
H1, H2, H3, H7, H8, H9, H10: HOLE
H4, H5, H6: FEET
P1: CONN_01X03
P2: CONN_2
P3, P4: CONN_01X02
Q1, Q2, Q3, Q4, Q5, Q6: 2N3904
R1, R2, R3, R4: 1k
R5, R9: 10k
R6, R7, R8, R10, R11, R12: 10

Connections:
GND: C1.2, C2.2, P1.1, Q1.1 (E), Q4.1 (E), R1.2, R2.2, R3.2, R4.2, R7.2, R11.2
HighBeamControl: D3.2 (K), D5.1 (A), D7.1 (A), D9.2 (K), P4.1
HighBeamSignal: D3.1 (A), D6.1 (A), P1.2
LowBeamControl: D2.1 (A), D4.2 (K), D8.2 (K), P2.2 (PM), P3.1
LowBeamSignal: D1.1 (A), D4.1 (A), P1.3
unnamed: Q1.3 (C), Q2.2 (B), Q3.2 (B), R5.2
unnamed: C2.1, D9.1 (A), P4.2, Q5.3 (C), Q6.3 (C), R9.1
unnamed: Q4.2 (B), R10.2, R11.1, R12.2
unnamed: Q5.1 (E), R10.1
unnamed: Q6.1 (E), R12.1
unnamed: C1.1, D8.1 (A), P3.2, Q2.3 (C), Q3.3 (C), R5.1
unnamed: Q3.1 (E), R8.1
unnamed: Q2.1 (E), R6.1
unnamed: Q1.2 (B), R6.2, R7.1, R8.2
unnamed: Q4.3 (C), Q5.2 (B), Q6.2 (B), R9.2
unnamed: D7.2 (K), R4.1
unnamed: D1.2 (K), R1.1
unnamed: D6.2 (K), R3.1
unnamed: D5.2 (K), P2.1
unnamed: D2.2 (K), R2.1

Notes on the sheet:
Low Beam Relay Coil
Jumper keeps low beams on when high beams engaged.
HOLD current (CC 65mA)
PICK current
High Beam Relay Coil
If Schottky diodes are not on hand, common rectifier diodes may be substituted (e.g. 1N4001). This will slightly worsen the low-voltage performance of the circuit (the relays may no longer work below 12 Volts).
If your relays don't PICK at low voltages, try substituting 470uF capacitors.

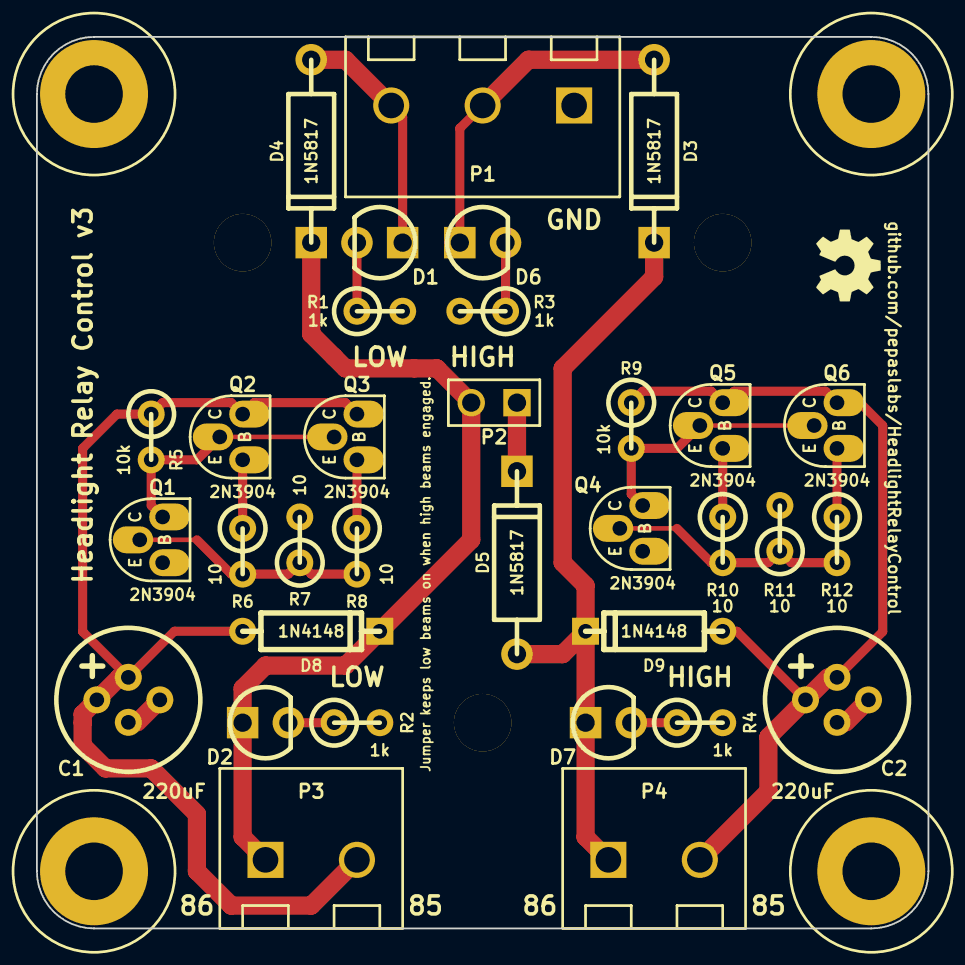
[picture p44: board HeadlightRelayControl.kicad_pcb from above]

Board: 2 copper layers, 49.5 x 49.5 mm, 40 parts (0 on the bottom side), 20 nets.

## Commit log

2015-03-21 importing v1
    [HeadlightRelayControl-B_Cu.gbl, HeadlightRelayControl-B_Mask.gbs, HeadlightRelayControl-B_SilkS.gbo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]
2015-03-21 bugfix: a 1/4 watt resistor was seeing 500mW. broke it up into four 1/4w resistors. this is release v2.
    [HeadlightRelayControl-B_Cu.gbl, HeadlightRelayControl-B_Mask.gbs, HeadlightRelayControl-B_SilkS.gbo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]
2015-03-22 removing extraneous transistors. updated board labelling.
    [HeadlightRelayControl.kicad_pcb, HeadlightRelayControl.sch]
2015-03-22 Added corner mounting holes.
    [HeadlightRelayControl-B_Cu.gbl, HeadlightRelayControl-B_Mask.gbs, HeadlightRelayControl-B_SilkS.gbo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]
2015-03-22 creating PDF of schematic
    [HeadlightRelayControl.sch]
2015-03-22 renaming schematic file (and copying to releases/v2)
2015-03-22 renaming schematic
2015-03-22 adding gerber renders (courtesy of OSHPark).
2015-03-22 adding ltspice schematic
2015-03-24 adding v3 board design with constant current sinks on relay coils.
    [HeadlightRelayControl-B_Cu.gbl, HeadlightRelayControl-B_Mask.gbs, HeadlightRelayControl-B_SilkS.gbo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]
2015-03-24 adding board renders
2015-04-02 using update terminal block footprints.
    [HeadlightRelayControl-B_Cu.gbl, HeadlightRelayControl-B_Mask.gbs, HeadlightRelayControl-B_SilkS.gbo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]
2015-04-02 changing 1N4001 diodes to schottky 1N5817. updating diode footprints. adding substitution notes to schematic.
    [HeadlightRelayControl-B_Cu.gbl, HeadlightRelayControl-B_Mask.gbs, HeadlightRelayControl-B_SilkS.gbo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]
2015-04-02 updating board renders.
